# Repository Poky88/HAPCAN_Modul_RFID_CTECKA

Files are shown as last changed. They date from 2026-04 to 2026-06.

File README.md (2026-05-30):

# HAPCAN Extension Module - NFC Tag Reader

This repository contains complete hardware and software resources for the development and implementation of a new extension module for the HAPCAN home automation system. The module enables contactless user identification using RFID technology and subsequent control of smart home output elements via the CAN bus. This project was created as part of a bachelor's thesis.

<p align="center">
  PCB - Module-3D-TOP
  <br>
  <i>Fig. 1: Module - 3D visualization</i>
</p>

## Features
- <ins>Contactless control:</ins> Output actuator control using RFID technology
- <ins>Access management:</ins> Setting access rights via the official HAPCAN Programmer application
- <ins>Universal output:</ins> Ability to control any actuator operating at 24 V
- <ins>Easy installation:</ins> Housed in a protective enclosure for standard in-wall flush-mount electrical boxes
- <ins>Connection options:</ins> The module can be connected to the CAN bus using an RJ45 connector or a screw terminal block
- <ins>Full compatibility:</ins> The device respects the HAPCAN protocol and communicates seamlessly with it
- <ins>Tag indication:</ins> Indicator LEDs signal when a tag is scanned

# Hardware
The schematic design and printed circuit board (PCB) layout were created using KiCad. All project source files and complete manufacturing files are available in the respective folders.

| PCB Model - TOP | PCB Model - BOT |
| :---: | :---: |
| PCB - JLCPCB - TOP | PCB - JLCPCB - BOT|
<p align="center">
  <i> Fig. 2: PCB module visualization </i>
</p>

# Software

The complete firmware was developed in the Arduino IDE environment and is divided into two main parts. The operation of the NFC reader is handled by the `Hapcan_NFC.cpp` source file. CAN bus communication, module configuration, and interaction with the Hapcan Programmer application are managed by the second source file, `HapcanProtocol.cpp`. Both parts include corresponding header files for function declarations and library imports. To help understand the core program logic, flowchart diagrams of both main processes are provided below. The complete source codes are located in the attached folder.

<p align="center">
  Hapcan_NFC-flowchart drawio
  <br>
  <i>Fig. 3: Flowchart - NFC Reader Operation</i>
</p>

<p align="center">
  HapcanProtocol-flowchart drawio (1)
  <br>
  <i>Fig. 4: Flowchart - HAPCAN Protocol Operation</i>
</p>

# Module Construction

The complete module is housed inside a custom-designed protective enclosure. This case serves not only a protective function but also secures the NFC reader in the optimal position for reliable tag scanning. The fully assembled module is designed for easy mounting into a standard flush-mount in-wall electrical box. A detailed assembly and installation guide is described in the attached documentation, and the 3D models required for manufacturing the enclosure are included in the electronic appendices of the thesis. 

The following diagram illustrates an example wiring diagram using an electric lock. For correct operation, the module must be connected to the CAN bus and linked with a Button module.

<p align="center">

  <br>
  <i>Fig. 5: Typical wiring diagram</i>
</p>

<p align="center">
  Typical module assembly
  <br>
  <i>Fig. 6: Assembled module</i>
</p>

# File Structure

<pre>
Hardware
└── KiCad 9.0                  # PCB design projects
    ├── production
    ├── Module - DPS.kicad_pcb
    ├── Module - DPS.kicad_pro
    └── Module - DPS.kicad_sch
Software
└── Arduino IDE 2.3.8          # Firmware source files
    └── HAPCAN
        ├── HAPCAN.ino
        ├── HAPCAN_NFC.cpp
        ├── HAPCAN_NFC.h
        ├── HAPCANProtocol.cpp
        └── HAPCANProtocol.h
3D printing
└── Inventor 2026              # 3D model of the protective enclosure
    ├── Cover - top part.ipt
    ├── Cover - assembly.iam
    └── Cover - bottom.ipt

Documentacion                  # PDF documentation of the module
    └── Documentation.pdf
</pre>

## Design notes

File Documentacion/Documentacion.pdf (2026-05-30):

NFC Tag Reader

## 1 Features

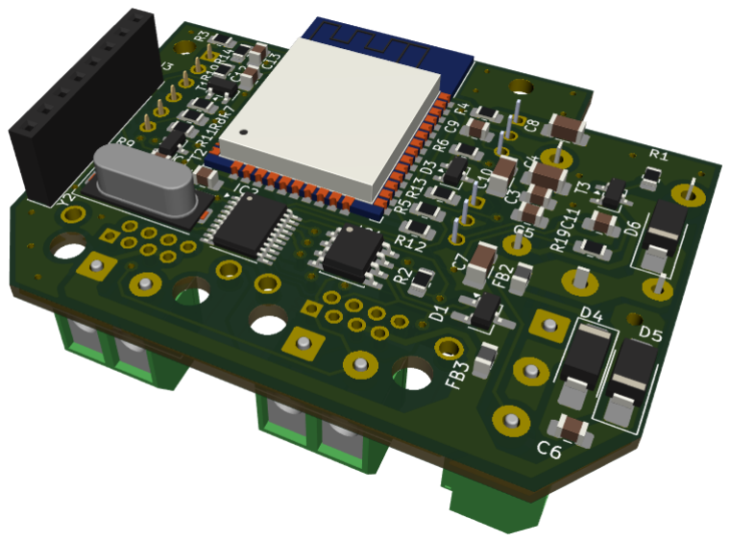
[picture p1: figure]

- Control of an output actuator using NFC tags
- Access rights evaluation
- Designed for a 24V actuator
- Flush-mounted installation in an electrical box
- Bus connection via RJ45 or screw terminals
- Tag reading indication

## 2 Device Description

This universal module serves as an end device for contactless access control and output actuator management (e.g., an electrical lock). The device is designed with an emphasis on full compatibility with the HAPCAN protocol, allowing for easy and reliable integration into this system. The device functions exclusively as a peripheral that facilitates tag reading and the physical triggering of the lock, while the actual verification of access rights can be configured in the HAPCAN Programmer application. After the physical reading of the identification tag, the data is sent over the bus for further processing within the system. The module triggers the output device only upon receiving the appropriate control message.

### 2.1 Complete Documentation

Complete manufacturing documentation for the hardware, firmware source codes, and 3D printing data for the protective cover are freely available on the GitHub platform at the following link: https: //github.com/Poky88/HAPCAN_Modul_RFID_CTECKA

## 3 Hardware

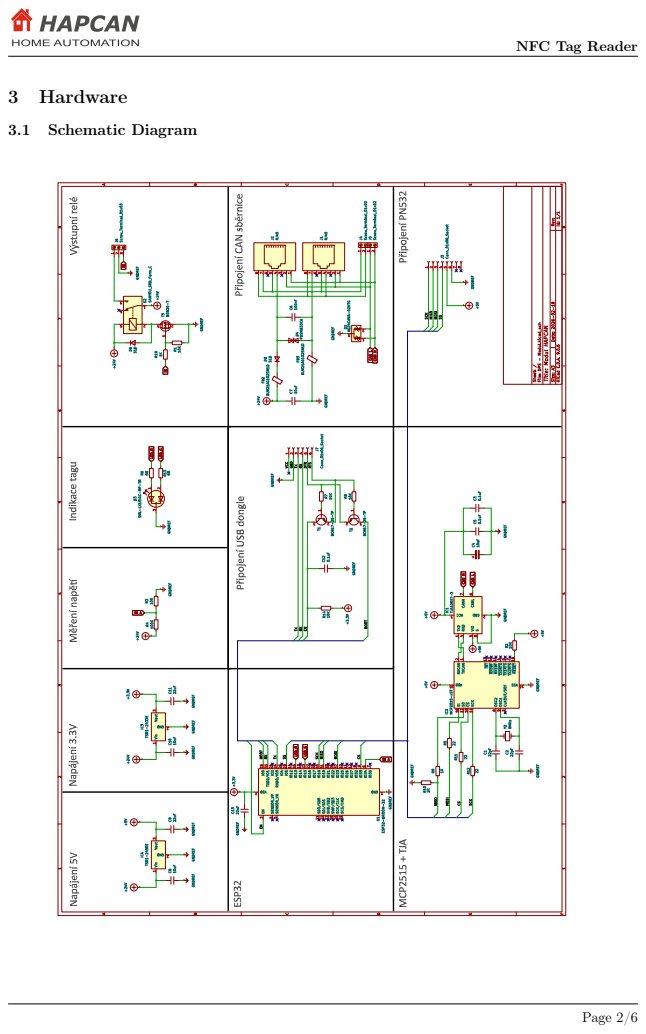
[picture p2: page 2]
3.1 Schematic Diagram

### 3.2 Bill of Materials

Reference | Component | Value | Quantity | Footprint
IC4 | DC/DC Converter | 5V | 1 | 3-SIP module
IC3 | DC/DC Converter | 3,3V | 1 | 3-SIP module
R4 | SMD Resistor | 100k | 1 | 0805
R1,R2,R3,R7,R8,R14 | SMD Resistor | 10k | 6 | 0805
R10 | SMD Resistor | 2k | 1 | 0805
D5, D6 | Rectifier Diode | - | 2 | DO-214AC, SMA
K2 | Relay | 24V | 1 | SRD, C
R9, R19 | SMD Resistor | 1k | 2 | 0805
T3 | MOSFET Transistor | - | 1 | SOT-23
U1 | ESP32-WROOM-32E | - | 1 | 38-SMD module
T1, T2 | NPN Transistor | - | 2 | SOT-23
C3, C5, C6, C12 | SMD Capacitor | 0,1uF | 4 | 0805
FB2, FB3 | Ferrite Bead | - | 2 | 0805
D4 | Protection Diode | - | 1 | DO-214AC, SMA
D1 | Protection Diode | - | 1 | SOT-23
R5, R11, R12 | SMD Resistor | 22 | 3 | 0805
C1, C2 | SMD Capacitor | 22pF | 2 | 0805
Y2 | Crystal | 8MHz | 1 | HC-49
IC2 | MCP2515T-I/ST | - | 1 | 20-TSSOP
IC1 | TJA1051T/3/2Z | - | 1 | 8-SOIC
C4 | SMD Capacitor | 10uF | 1 | 1206
(C7), C8, C10 | SMD Capacitor | 10uF | 2-3 | 1206
C9, C11 | SMD Capacitor | 22uF | 2 | 0805
D3 | Indicator LED | - | 1 | SOT-23
R6, R13 | SMD Resistor | 68 | 2 | 0805
J4, J5 | Terminal Block | - | 2 | 10.5x7.8, 5mm raster
J6 | Terminal Block | - | 1 | 15.5x7.8, 5mm raster
J3 | Pin Header | - | 1 | 1x08, 2.54mm raster
J7 | Pin Header | - | 1 | 1x06, 2.54mm raster
J1, J2 | RJ45 Connector | - | 2 | RJHSE5380

Table 1: Bill of Materials

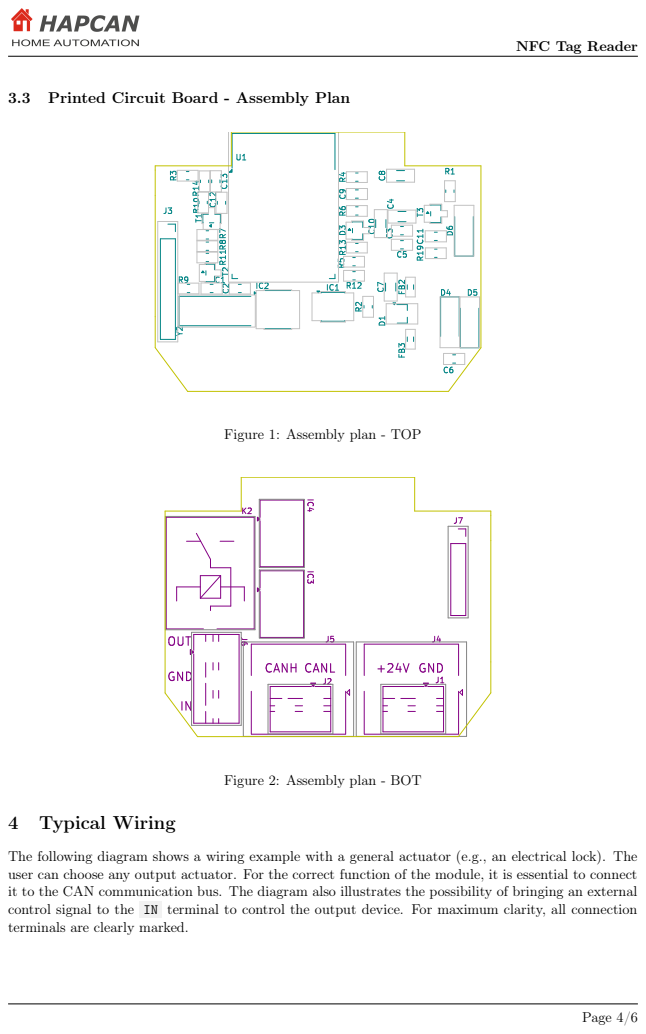
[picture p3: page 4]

3.3 Printed Circuit Board - Assembly Plan C¹³ R¹⁰ R¹⁴

Figure 1: Assembly plan - TOP OUT GND

Figure 2: Assembly plan - BOT

The following diagram shows a wiring example with a general actuator (e.g., an electrical lock). The
user can choose any output actuator. For the correct function of the module, it is essential to connect
it to the CAN communication bus. The diagram also illustrates the possibility of bringing an external
control signal to the IN terminal to control the output device. For maximum clarity, all connection
terminals are clearly marked.

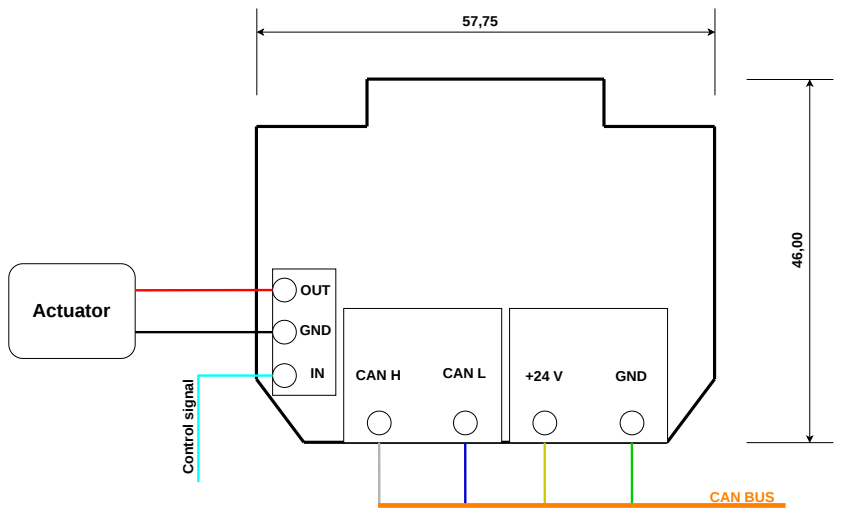
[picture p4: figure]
CAN H; CAN L; GND; OUT; Control signal; CAN BUS; Actuator

Figure 3: Typical wiring

### 4.1 Installation into an Electrical Box

The device is first placed into a protective cover, which, in addition to mechanical protection, also ensures the correct fixation and positioning of the reader. To successfully install the entire module into a flush-mounted electrical box, some of its internal plastic parts must be removed. The extent of these modifications always depends on the specific type of box used. The following figures show the progress of these modifications and their final result.

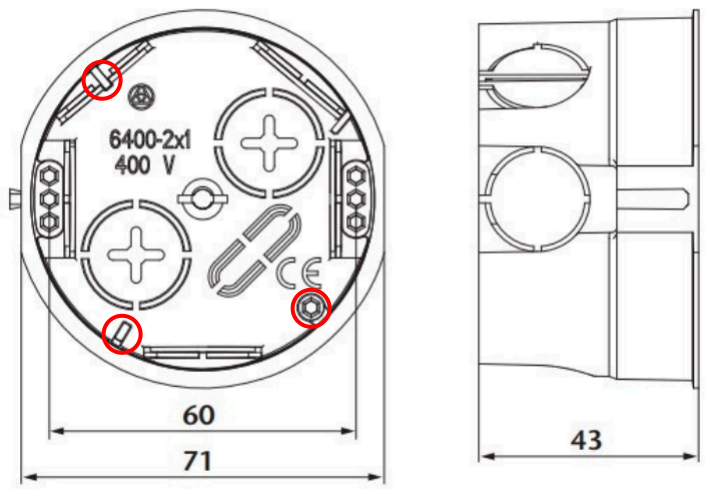
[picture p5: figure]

Figure 4: Removal of obstructing parts

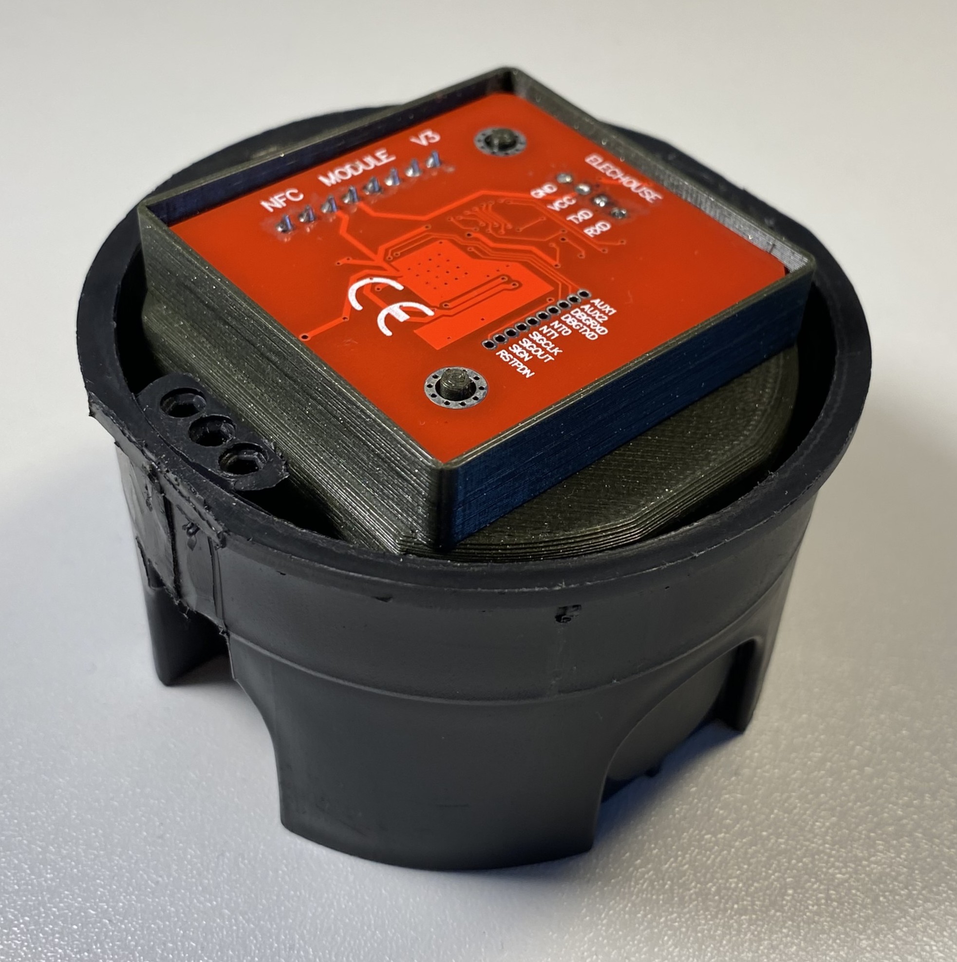
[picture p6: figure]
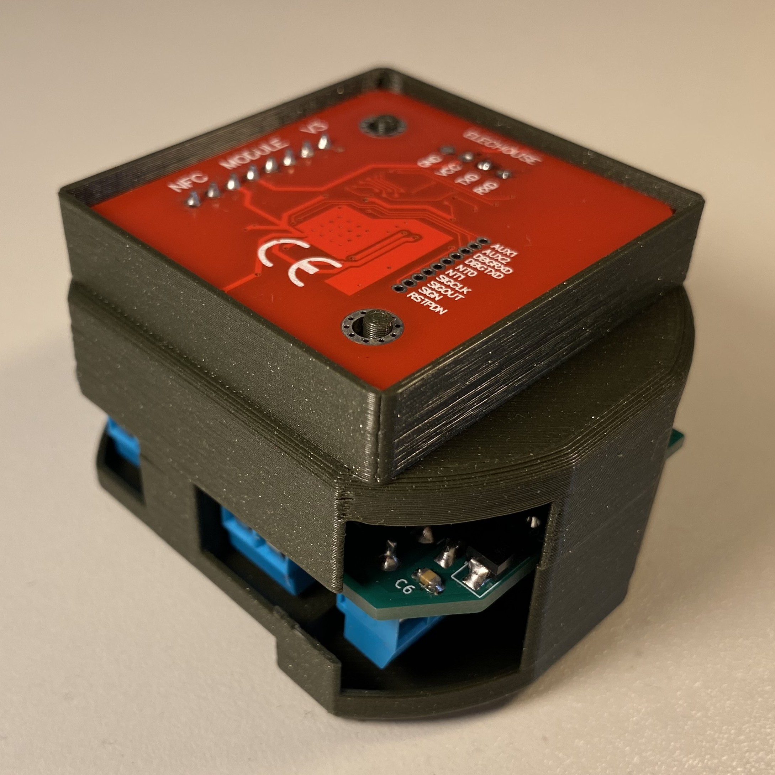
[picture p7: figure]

(a) Fully assembled module | (b) Module placed in the box

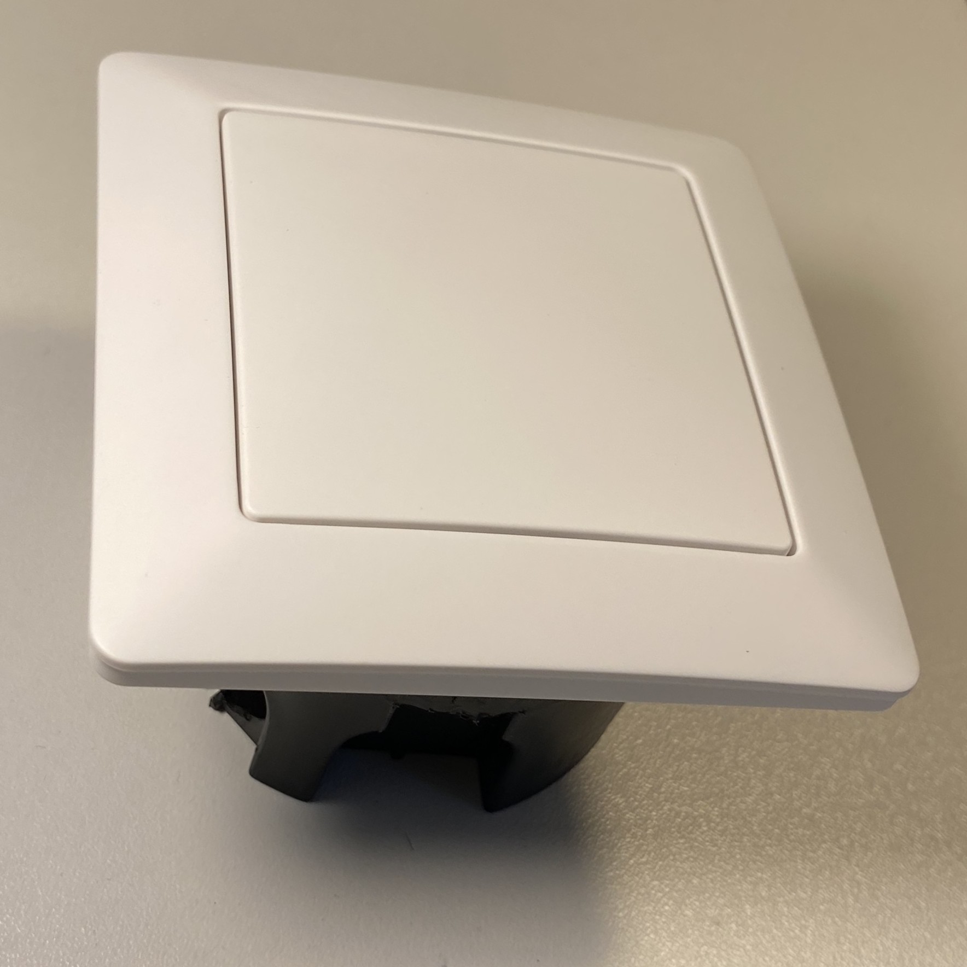
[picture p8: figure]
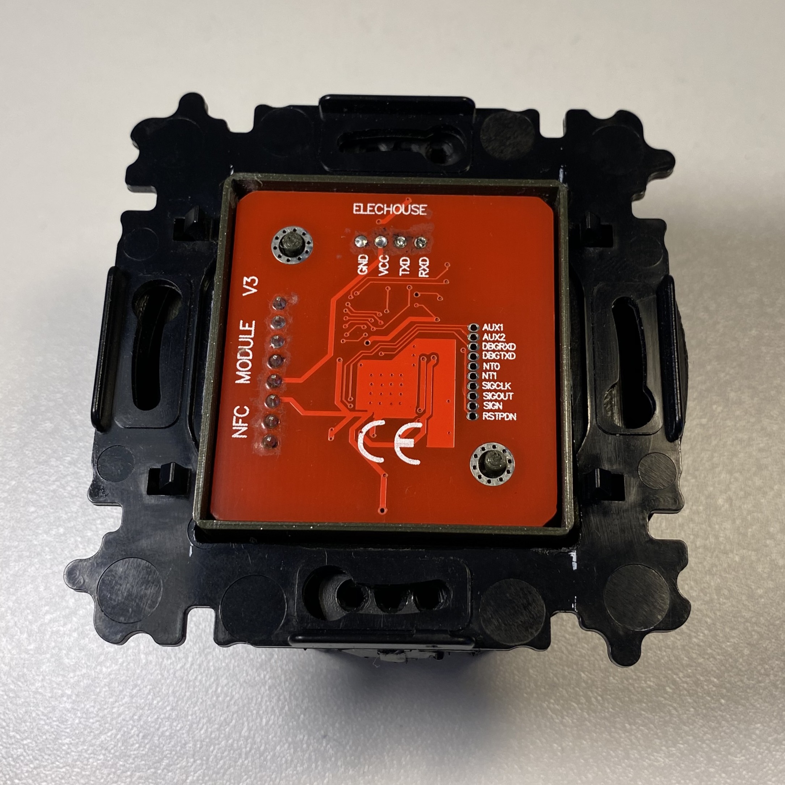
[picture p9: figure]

(c) Grid on the box | (d) Complete installation

Figure 5: Module installation into an electrical box

## 5 License

HAPCAN is a trademark of its respective owners. This project is an independent implementation compatible with the HAPCAN system.
This hardware is free hardware: you can redistribute it and/or modify it under the terms of the GNU General Public License as published by the Free Software Foundation, either version 3 of the License, or (at your option) any later version.

This hardware is distributed in the hope that it will be useful, but WITHOUT ANY WARRANTY; without even the implied warranty of MERCHANTABILITY or FITNESS FOR A PARTICULAR PURPOSE. See the GNU General Public License for more details.

You should have received a copy of the GNU General Public License along with this program. If not, see http://www.gnu.org/licenses/gpl-3.0.html.

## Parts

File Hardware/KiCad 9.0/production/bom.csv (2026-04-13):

Designator | Footprint | Quantity | Value | LCSC Part #
C1, C2 | 0805 | 2 | 22pF
C10, C4, C7, C8 | 1206 | 4 | 10uF
C11, C13, C9 | 0805 | 3 | 22uF
C12 | 0805 | 1 | 0,1uF
C3, C5 | 0805 | 2 | 0.1uF
C6 | 0805 | 1 | 100nF
D1 | SC-59_Handsoldering | 1 | AQ24CANA-02HTG
D3 | SOT-23-3 | 1 | SML-LX15IGC-RP-TR
D4 | D_SMA_Handsoldering | 1 | P6SMB33CA
D5, D6 | D_SMA_Handsoldering | 2 | S1D
FB2, FB3 | 0805 | 2 | BLM21AG102SN1D
IC1 | SOIC-8_3.9x4.9mm_P1.27mm | 1 | TJA1051T-3
IC2 | TSSOP-20_4.4x6.5mm_P0.65mm | 1 | MCP2515-xST
IC3 | Converter_DCDC_TRACO_TSR1-xxxxE_THT | 1 | TSR1-2433E
IC4 | Converter_DCDC_TRACO_TSR1-xxxxE_THT | 1 | TSR1-2450E
J1, J2 | RJ45_Amphenol_RJHSE5380 | 2 | RJ45
J3 | PinSocket_1x08_P2.54mm_Vertical | 1 | Conn_01x08_Socket
J4, J5 | TerminalBlock_MaiXu_MX126-5.0-02P_1x02_P5.00mm | 2 | Screw_Terminal_01x02
J6 | TerminalBlock_MaiXu_MX126-5.0-03P_1x03_P5.00mm | 1 | Screw_Terminal_01x03
J7 | PinSocket_1x06_P2.54mm_Vertical | 1 | Conn_01x06_Socket
K2 | Relay_SPDT_SANYOU_SRD_Series_Form_C | 1 | SANYOU_SRD_Form_C
R1, R14, R2, R3, R7, R8 | 0805 | 6 | 10K
R10 | 0805 | 1 | 2K
R11, R12, R5 | 0805 | 3 | 22
R13, R6 | 0805 | 2 | 68
R19, R9 | 0805 | 2 | 1K
R4 | 0805 | 1 | 100K
T1, T2 | SOT-23 | 2 | BC817-25-TP
T3 | SOT-23-3 | 1 | BSN20-7
U1 | ESP32-WROOM-32 | 1 | ESP32-WROOM-32
Y2 | Crystal_SMD_HC49-SD | 1 | 8MHz

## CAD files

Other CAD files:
3D printing/Inventor 2026/Kryt_horni_dil.ipt
3D printing/Inventor 2026/Kryt_soustava.iam
3D printing/Inventor 2026/Kryt_spodni_dil.ipt

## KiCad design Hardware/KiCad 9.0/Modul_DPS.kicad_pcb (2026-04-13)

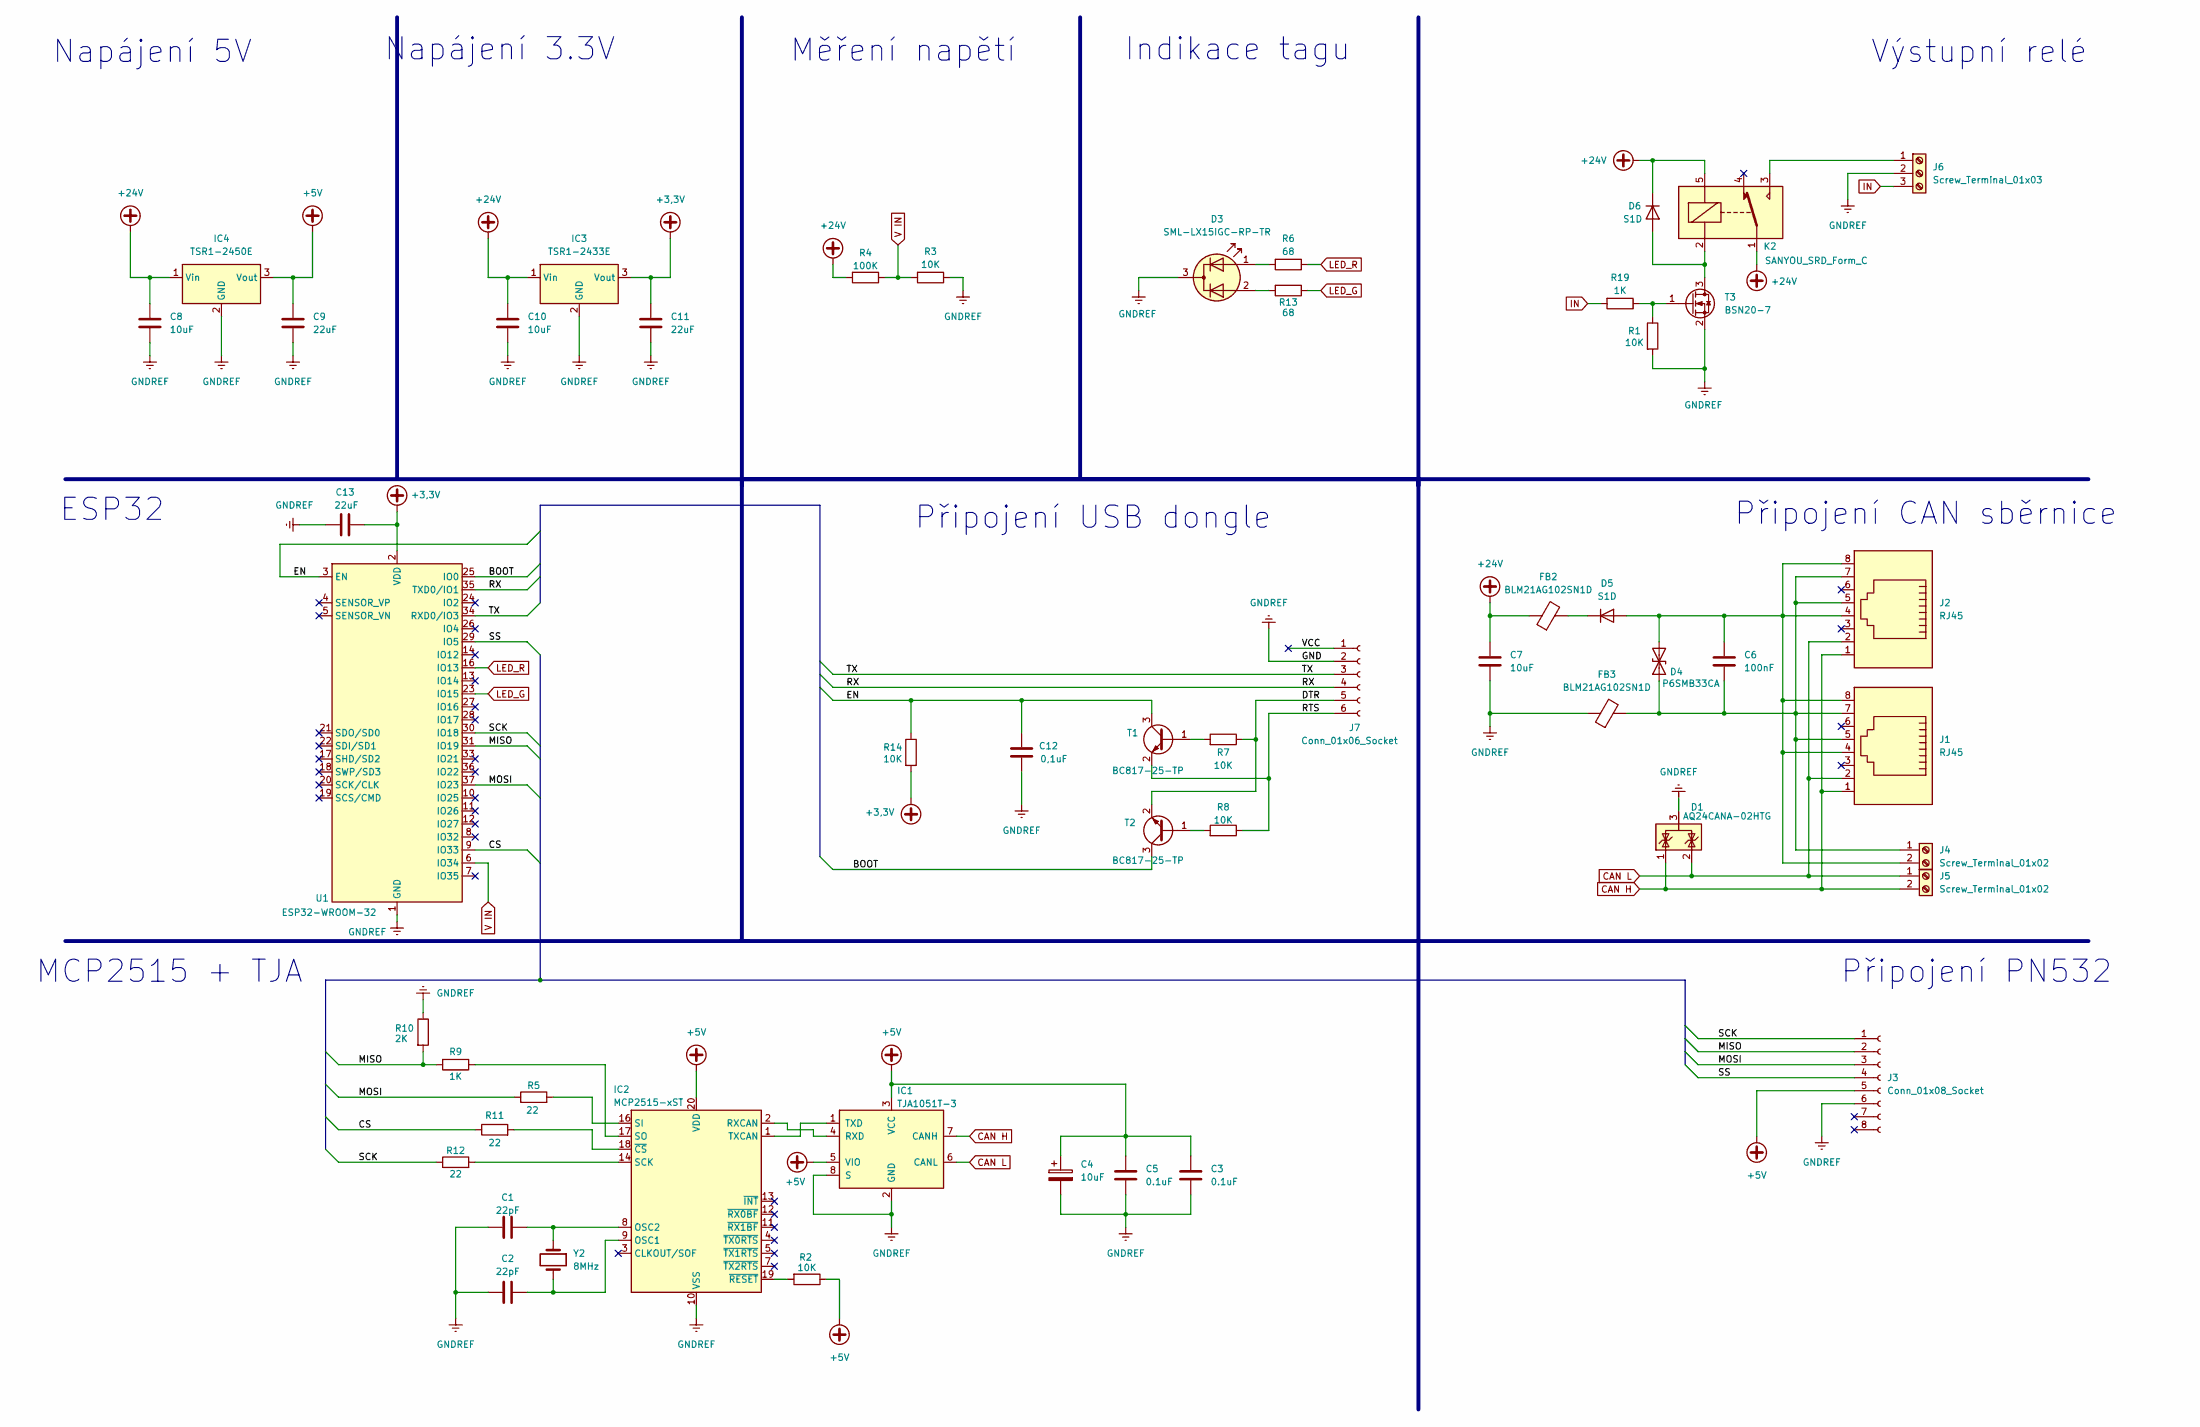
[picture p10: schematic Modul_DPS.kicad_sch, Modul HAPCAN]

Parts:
C1, C2: 22pF; C_0805_2012Metric_Pad1.18x1.45mm_HandSolder
C3, C5: 0.1uF; C_0805_2012Metric_Pad1.18x1.45mm_HandSolder
C4, C7, C8, C10: 10uF; C_1206_3216Metric_Pad1.33x1.80mm_HandSolder
C6: 100nF; C_0805_2012Metric_Pad1.18x1.45mm_HandSolder
C9, C11, C13: 22uF; C_0805_2012Metric_Pad1.18x1.45mm_HandSolder
C12: 0,1uF; C_0805_2012Metric_Pad1.18x1.45mm_HandSolder
D1: AQ24CANA-02HTG; SC-59_Handsoldering
D3: SML-LX15IGC-RP-TR; SOT-23-3
D4: P6SMB33CA; D_SMA_Handsoldering
D5, D6: S1D; D_SMA_Handsoldering
FB2, FB3: BLM21AG102SN1D; L_0805_2012Metric
IC1: TJA1051T-3; SOIC-8_3.9x4.9mm_P1.27mm
IC2: MCP2515-xST; TSSOP-20_4.4x6.5mm_P0.65mm
IC3: TSR1-2433E; Converter_DCDC_TRACO_TSR1-xxxxE_THT
IC4: TSR1-2450E; Converter_DCDC_TRACO_TSR1-xxxxE_THT
J1, J2: RJ45; RJ45_Amphenol_RJHSE5380
J3: Conn_01x08_Socket; PinSocket_1x08_P2.54mm_Vertical
J4, J5: Screw_Terminal_01x02; TerminalBlock_MaiXu_MX126-5.0-02P_1x02_P5.00mm
J6: Screw_Terminal_01x03; TerminalBlock_MaiXu_MX126-5.0-03P_1x03_P5.00mm
J7: Conn_01x06_Socket; PinSocket_1x06_P2.54mm_Vertical
K2: SANYOU_SRD_Form_C; Relay_SPDT_SANYOU_SRD_Series_Form_C
R1, R2, R3, R7, R8, R14: 10K; R_0805_2012Metric_Pad1.20x1.40mm_HandSolder
R4: 100K; R_0805_2012Metric_Pad1.20x1.40mm_HandSolder
R5, R11, R12: 22; R_0805_2012Metric_Pad1.20x1.40mm_HandSolder
R6, R13: 68; R_0805_2012Metric_Pad1.20x1.40mm_HandSolder
R9, R19: 1K; R_0805_2012Metric_Pad1.20x1.40mm_HandSolder
R10: 2K; R_0805_2012Metric_Pad1.20x1.40mm_HandSolder
T1, T2: BC817-25-TP; SOT-23
T3: BSN20-7; SOT-23-3
U1: ESP32-WROOM-32
Y2: 8MHz; Crystal_SMD_HC49-SD

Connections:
+5V: C3.2, C4.1, C5.2, C9.1, IC1.3 (VCC), IC1.5 (VIO), IC2.20 (VDD), IC4.3 (Vout), J3.5, R2.1
+24V: C7.1, C8.1, C10.1, D6.1 (K), FB2.1, IC3.1 (Vin), IC4.1 (Vin), K2.1, K2.5, R4.2
/BOOT: T2.3 (C), U1.25 (IO0)
/CS: R11.1, U1.9 (IO33)
/DTR: J7.5, R7.1, T2.2 (E)
/EN: C12.1, R14.1, T1.3 (C), U1.3 (EN)
/MISO: J3.2, R9.2, R10.2, U1.31 (IO19)
/MOSI: J3.3, R5.1, U1.37 (IO23)
/RTS: J7.6, R8.1, T1.2 (E)
/RX: J7.4, U1.35 (TXD0/IO1)
/SCK: J3.1, R12.1, U1.30 (IO18)
/SS: J3.4, U1.29 (IO5)
/TX: J7.3, U1.34 (RXD0/IO3)
/VCC: J7.1
CAN H: D1.1 (K), IC1.7 (CANH), J1.1, J2.1, J5.2
CAN L: D1.2 (K), IC1.6 (CANL), J1.2, J2.2, J5.1
IN: J6.3, R19.2
LED_G: R13.1, U1.23 (IO15)
LED_R: R6.1, U1.16 (IO13)
unnamed: D3.1 (A1), R6.2
unnamed: D3.2 (A2), R13.2
unnamed: C6.2, D4.1 (A1), FB3.2, J1.5, J1.7, J2.5, J2.7, J4.1
unnamed: C6.1, D4.2 (A2), D5.2 (A), J1.4, J1.8, J2.4, J2.8, J4.2
unnamed: D5.1 (K), FB2.2
unnamed: D6.2 (A), K2.2, T3.3 (D)
unnamed: IC1.4 (RXD), IC2.2 (RXCAN)
unnamed: IC1.1 (TXD), IC2.1 (TXCAN)
unnamed: C2.2, IC2.9 (OSC1), Y2.2
unnamed: C1.2, IC2.8 (OSC2), Y2.1
unnamed: IC2.14 (SCK), R12.2
unnamed: IC2.16 (SI), R5.2
unnamed: IC2.17 (SO), R9.1
unnamed: IC2.18 (~CS), R11.2
unnamed: IC2.19 (~RESET), R2.2
unnamed: J6.1, K2.3
unnamed: R7.2, T1.1 (B)
unnamed: R8.2, T2.1 (B)
unnamed: R1.1, R19.1, T3.1 (G)
V IN: R3.2, R4.1, U1.6 (IO34)

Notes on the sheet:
Indikace tagu
Připojení CAN sběrnice
Připojení USB dongle
Připojení PN532
Měření napětí
MCP2515 + TJA
Výstupní relé
Napájení 3.3V
ESP32
Napájení 5V

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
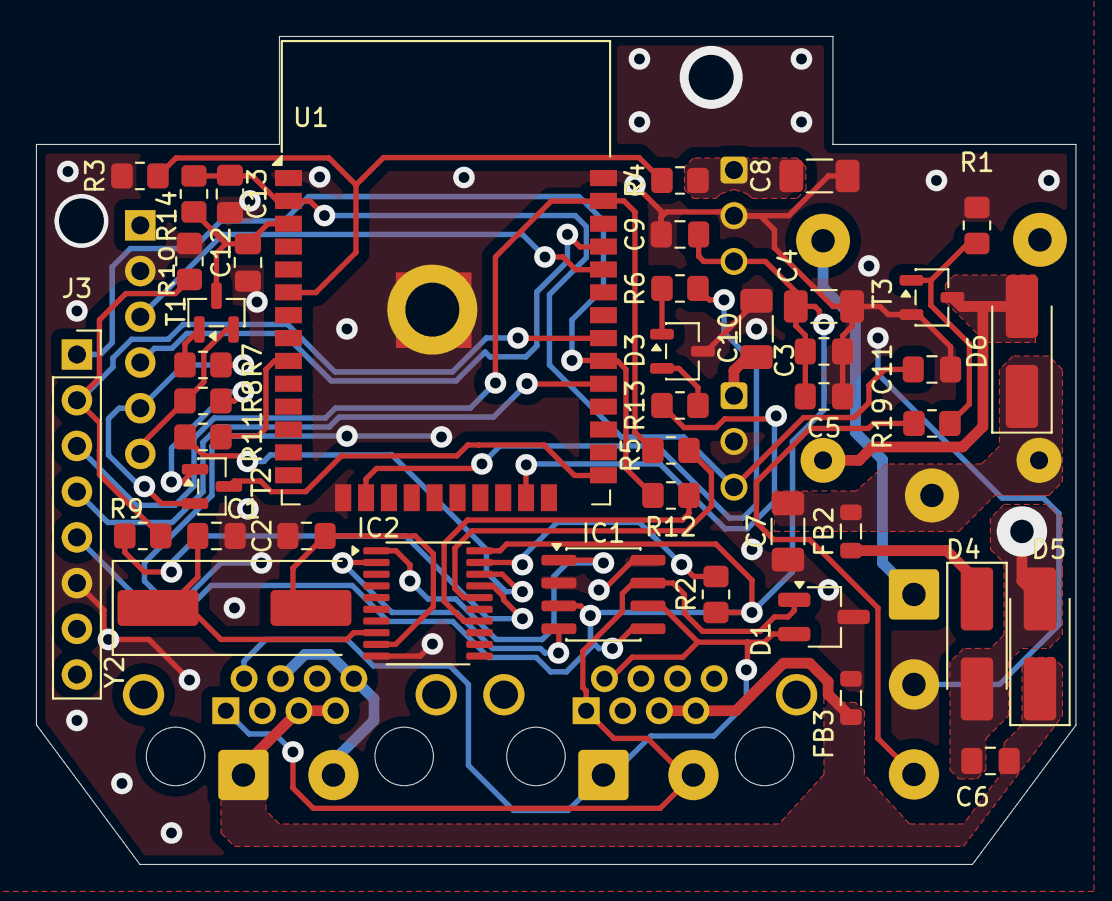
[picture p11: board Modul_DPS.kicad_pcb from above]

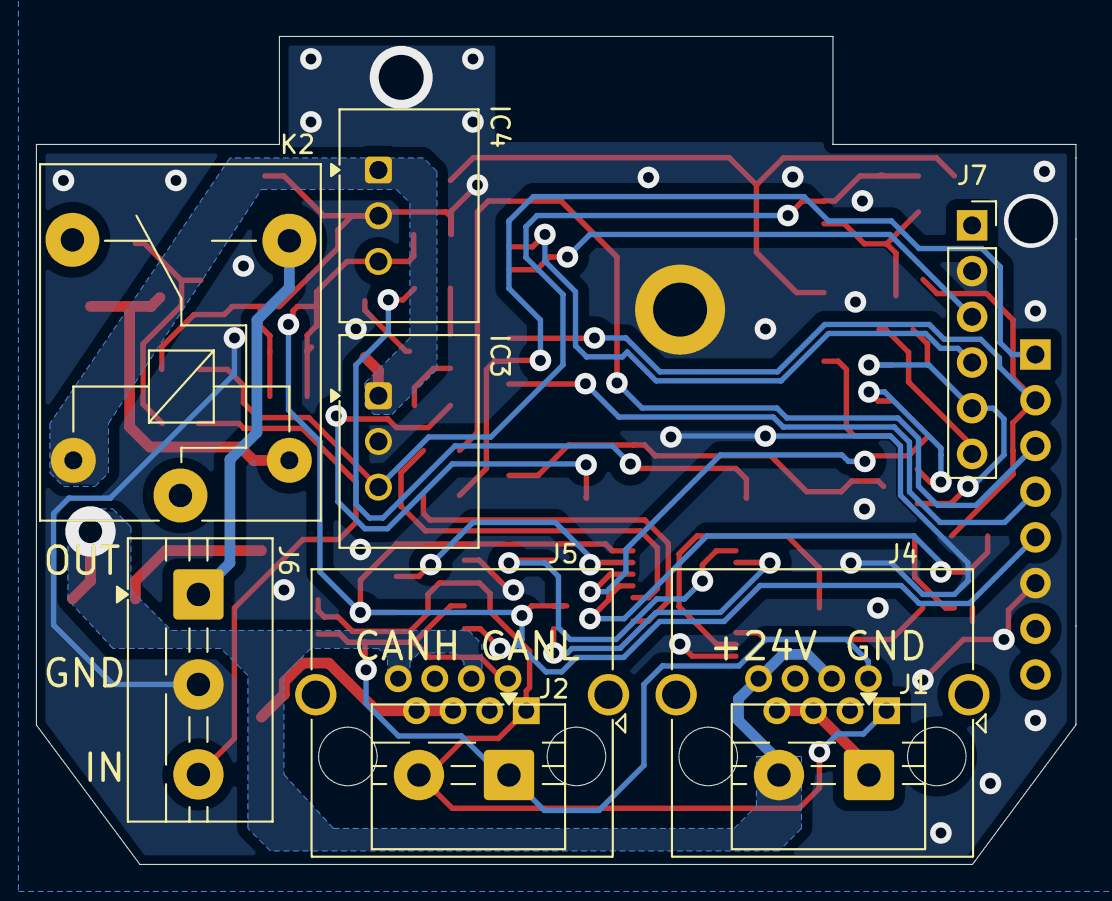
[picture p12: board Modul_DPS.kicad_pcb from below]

Board: 2 copper layers, 57.8 x 46.0 mm, 52 parts (9 on the bottom side), 40 nets.

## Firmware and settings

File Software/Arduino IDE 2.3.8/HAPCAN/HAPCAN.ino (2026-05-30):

#include <HapcanProtocol.h>
#include <Hapcan_NFC.h>

// Definice pinů CS na SPI sběrnici.
#define CAN_CS_PIN    33    // převodník CAN
#define PN532_CS      5     // čtečka MCP2515

// Definice pinů pro identifikační LED
#define LED_GREEN     13
#define LED_RED       15

// Výchozí hodnoty Node, Group a Description
#define DEFAULT_NODE  2
#define DEFAULT_GROUP 4
#define DEFAULT_DESC  "NFC Card Reader"

// Instance tříd spravující jednotlivé periferie
HapcanProtocol hapcanProto(CAN_CS_PIN);
HapcanNFC hapcanNfc(PN532_CS, LED_GREEN, LED_RED);

void setup() {
  Serial.begin(115200);
  delay(100);

 // Konfigurace CS pinů
  pinMode(CAN_CS_PIN, OUTPUT);
  digitalWrite(CAN_CS_PIN, HIGH);
  pinMode(PN532_CS, OUTPUT);
  digitalWrite(PN532_CS, HIGH);

  hapcanProto.begin(DEFAULT_NODE, DEFAULT_GROUP, DEFAULT_DESC);     // Spuštění CAN komunikace
  hapcanNfc.begin(&hapcanProto, 0x315);     // Spuštění NFC čtečky
}

void loop() {
  hapcanProto.loop();   // Kontrola přijatých zpráv na sběrnici
  if (!hapcanProto.isProgramming()) {   // Modul obsluhuje čtečku pouze když není v programovacím režimu
    hapcanNfc.loop();
  }
}

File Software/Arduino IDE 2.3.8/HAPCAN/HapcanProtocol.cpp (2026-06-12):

#include "HapcanProtocol.h"

// Virtuální adresy pro uložení Node, Group a Description
#define EEPROM_NODE_ADDR   0xF00026
#define EEPROM_GROUP_ADDR  0xF00027
#define EEPROM_DESC_ADDR   0xF00030

HapcanProtocol::HapcanProtocol(uint8_t csPin)
  : CAN0(csPin), my_serial(0x00120424), _progAddr(0), _progCmd(0), is_programming(false) {} 

void HapcanProtocol::begin(uint8_t defaultNode, uint8_t defaultGroup, const char* defaultDesc) {
  SPI.begin(18, 19, 23);      // Inicializace SPI (SCK=18, MISO=19, MOSI=23)
  prefs.begin("hapcan_cfg", false);     // Přístup do flash paměti
  loadConfig(defaultNode, defaultGroup, defaultDesc);

  // Inicializace CAN řadiče na rychlost 125 kbps
  if (CAN0.begin(MCP_ANY, CAN_125KBPS, MCP_8MHZ) == CAN_OK)
    CAN0.setMode(MCP_NORMAL);
  else
    while (1) delay(1000);
}

void HapcanProtocol::loadConfig(uint8_t defNode, uint8_t defGroup, const char* defDesc) {
  current_node = prefs.getUChar("node", defNode);     // Načtení dat. Pokud v paměti zatím nic není, použijí se defaultní
  current_group = prefs.getUChar("group", defGroup);
  size_t len = prefs.getBytes("desc", description, 16);
  
  // Ochrana proti nekompletnímu popisu
  if (len < 16) {
    memset(description, 0x00, 16);
    uint8_t copyLen = strlen(defDesc) > 16 ? 16 : strlen(defDesc);
    memcpy(description, (const uint8_t*)defDesc, copyLen);
    prefs.putBytes("desc", description, 16);      // Zápis řetězce do paměti
  }
}

void HapcanProtocol::saveDescription() {
  prefs.putBytes("desc", description, 16);
}

void HapcanProtocol::loop() {
  // CAN_MSGAVAIL indikuje, že je v MCP2515 minimálně jedna nepřečtená zpráva
  while (CAN0.checkReceive() == CAN_MSGAVAIL) {
    uint32_t rxId;
    uint8_t len = 0;
    uint8_t rxBuf[8] = {0};
    CAN0.readMsgBuf(&rxId, &len, rxBuf);    // Vyčtení zprávy do lokálních proměnných
    processMsg(rxId, rxBuf);
  }
}

void HapcanProtocol::processMsg(uint32_t rxId, uint8_t *data) {
  // Bitové vymaskování horních 3 bitů, na 29 bitů
  uint32_t realRxId = rxId & 0x1FFFFFFF;
  if ((realRxId & (1UL << 16)) != 0) {
      return; 
  }
  // Získání typu zprávy
  uint32_t msgType = (uint32_t)((realRxId >> 17) & 0xFFF);

  // Požadavek na vstup do programovacího režimu
  if (msgType == 0x100) {
      // Modul vstoupí do režimu pouze, pokud data obsahují jeho stávající Node a Group
      if (data[2] == current_node && data[3] == current_group) {
          is_programming = true;
          // Odeslání potvrzovací odpovědi.
          uint8_t resp[8] = { current_node, current_group, 0xFF,0xFF,0xFF,0xFF,0xFF,0xFF };
          sendFrame(0x100, resp);
      }
      return;
  }

  // Restart nebo ukončení programovacího režimu
  if (msgType == 0x010 || msgType == 0x020) {
      if (is_programming) {
          is_programming = false;
          // Uložení změn z mezipaměti do paměti FLASH
          prefs.putUChar("node", current_node);
          prefs.putUChar("group", current_group);
          saveDescription();
      }
      return;
  }

  // zápis/čtení do paměti
  if (msgType == 0x030) {
      if (!is_programming) return;
      // Adresa v paměti
      _progAddr = ((uint32_t)data[0] << 16) | ((uint32_t)data[1] << 8) | data[2];
      _progCmd = data[5];
      sendFrame(0x030, data);
      return;
  }

  // Operace s pamětí
  if (msgType == 0x040) {
      if (!is_programming) return; 
      if (_progCmd == 0x02) {     // Zápis
          uint8_t next_n = current_node;
          uint8_t next_g = current_group;
          for (uint8_t i = 0; i < 8; i++) {
              if (data[i] == 0xFF) continue; 
              uint32_t addr = _progAddr + i;
              if (addr == EEPROM_NODE_ADDR) next_n = data[i];
              else if (addr == EEPROM_GROUP_ADDR) next_g = data[i];
              else if (addr >= EEPROM_DESC_ADDR && addr <= EEPROM_DESC_ADDR + 15)
                  description[addr - EEPROM_DESC_ADDR] = data[i];
          }
          sendFrame(0x040, data);
          current_node = next_n;
          current_group = next_g;
          return;
      }
      if (_progCmd == 0x01) {   // Čtení
          uint8_t resp[8]; memset(resp, 0xFF, 8); 
          for (uint8_t i = 0; i < 8; i++) {
              uint32_t addr = _progAddr + i;
              if (addr == EEPROM_NODE_ADDR) resp[i] = current_node;
              else if (addr == EEPROM_GROUP_ADDR) resp[i] = current_group;
              else if (addr >= EEPROM_DESC_ADDR && addr <= EEPROM_DESC_ADDR + 15)
                  resp[i] = description[addr - EEPROM_DESC_ADDR];
          }
          sendFrame(0x040, resp);
          return;
      }
  }

  uint8_t targetNode = data[2];
  uint8_t targetGroup = data[3];

// Musí být v programovacím režimu a určena pro tento modul
if ((targetGroup != current_group && targetGroup) || (targetNode != current_node && targetNode) || is_programming) return;

  // Jednotlivé dotazy
  switch (msgType) {
    case 0x103:
    case 0x104:
      sendHardwareResponse(msgType);
      break;
    case 0x105:
    case 0x106:
      sendFirmwareResponse(msgType);
      break;
    case 0x10B:
    case 0x10C:
      sendVoltageResponse(msgType);
      break;
    case 0x10D:
    case 0x10E:
      sendDescriptionResponse(msgType);
      break;
  }
}

// Jednotlivé definice odpovědí na dotazy
void HapcanProtocol::sendFrame(uint32_t type, uint8_t *data) {
  uint32_t id = ((uint32_t)type << 17) | (1UL << 16) | ((uint32_t)current_node << 8) | current_group;
  CAN0.sendMsgBuf(id, 1, 8, data);
}

void HapcanProtocol::sendEvent(uint32_t type, uint8_t *data) {
  uint32_t id = ((uint32_t)type << 17) | (0UL << 16) | ((uint32_t)current_node << 8) | current_group;
  CAN0.sendMsgBuf(id, 1, 8, data);
}

void HapcanProtocol::sendHardwareResponse(uint32_t reqType) {
  uint8_t d[8] = { 0x30, 0x00, 0x03, 0xFF, 0x00, 0x12, 0x04, 0x24 }; 
  sendFrame(reqType, d);
}

void HapcanProtocol::sendFirmwareResponse(uint32_t reqType) {
  uint8_t d[8] = { 0x30, 0x00, 0x08, 0x01, 0x00, 0x00, 0x00, 0x00 }; 
  sendFrame(reqType, d);
}

void HapcanProtocol::sendDescriptionResponse(uint32_t reqType) {
   uint8_t d[8];
   // Rozdělení Description do dvou zpráv
   memcpy(d, description, 8);
   sendFrame(0x10D, d);
   delay(40); 
   memcpy(d, description + 8, 8);
   sendFrame(0x10D, d); 
}

void HapcanProtocol::sendVoltageResponse(uint32_t reqType) {    // Měření napětí
  const uint8_t analogPin = 34; 
  analogReadResolution(12); 
  
  // Konstanty napěťového děliče
  constexpr float R1 = 100000.0f; 
  constexpr float R2 = 10000.0f; 
  
  constexpr float VBUS_FACTOR = (3.3f / 4095.0f) * ((R1 + R2) / R2) * (65472.0f / 30.5f);

  uint16_t v_bus = (uint16_t)(analogRead(analogPin) * VBUS_FACTOR);
  
  uint8_t d[8];
  d[0] = (uint8_t)(v_bus >> 8);
  d[1] = (uint8_t)(v_bus & 0xFF);
  d[2] = 0xFF; 
  d[3] = 0xFF;
  memset(d + 4, 0xFF, 4);

  sendFrame(reqType, d);
}
